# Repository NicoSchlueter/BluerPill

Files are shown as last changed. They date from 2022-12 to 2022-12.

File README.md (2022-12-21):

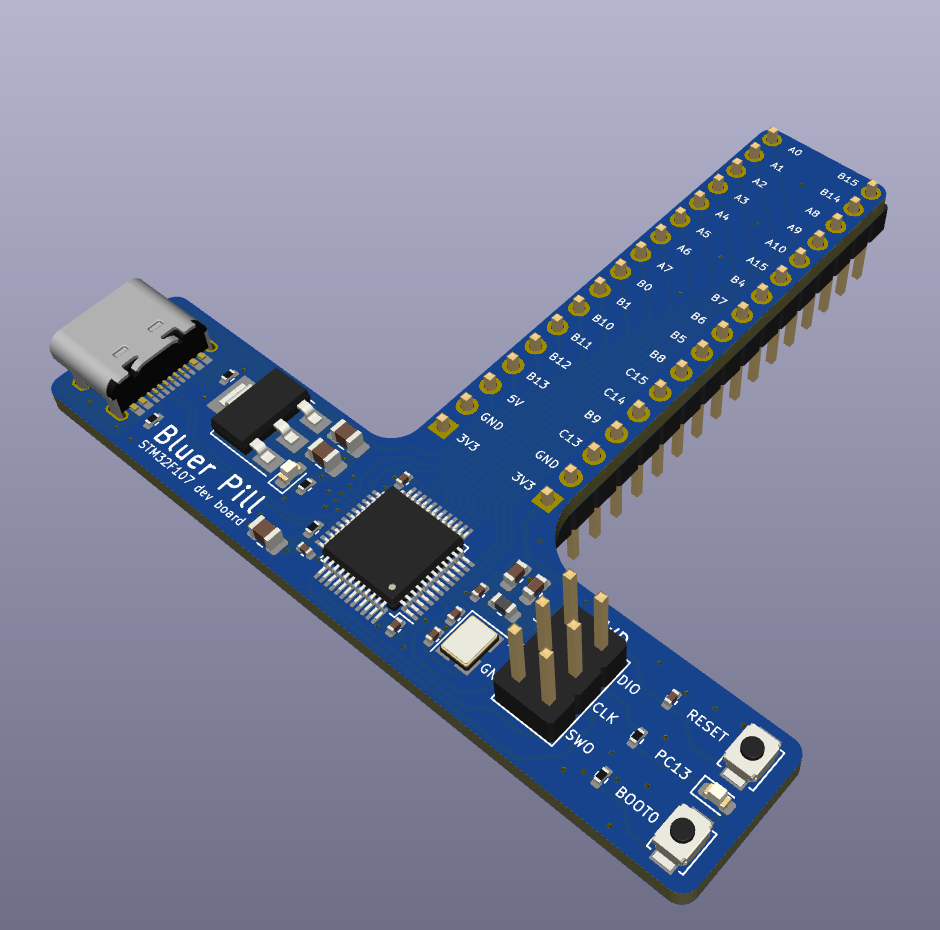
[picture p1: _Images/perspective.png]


Blue pill like STM32F103 dev board made to practice PCB design in KiCad following some Phil's lab tutorial.
 
# Things to improve
I am pretty happy with the schematic, but the routing on the board could definitly use quite some work.
I definitly underestimated the amount of signals that needed to go to the headers.

The board could probably have been designed as a two layer board as well.

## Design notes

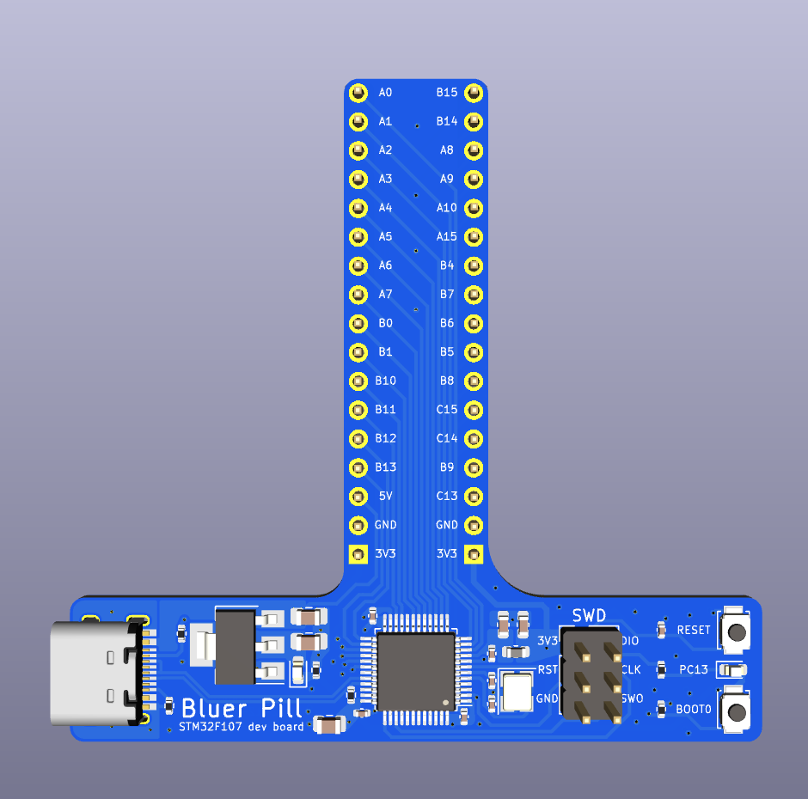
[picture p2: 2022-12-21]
_Images/top.png

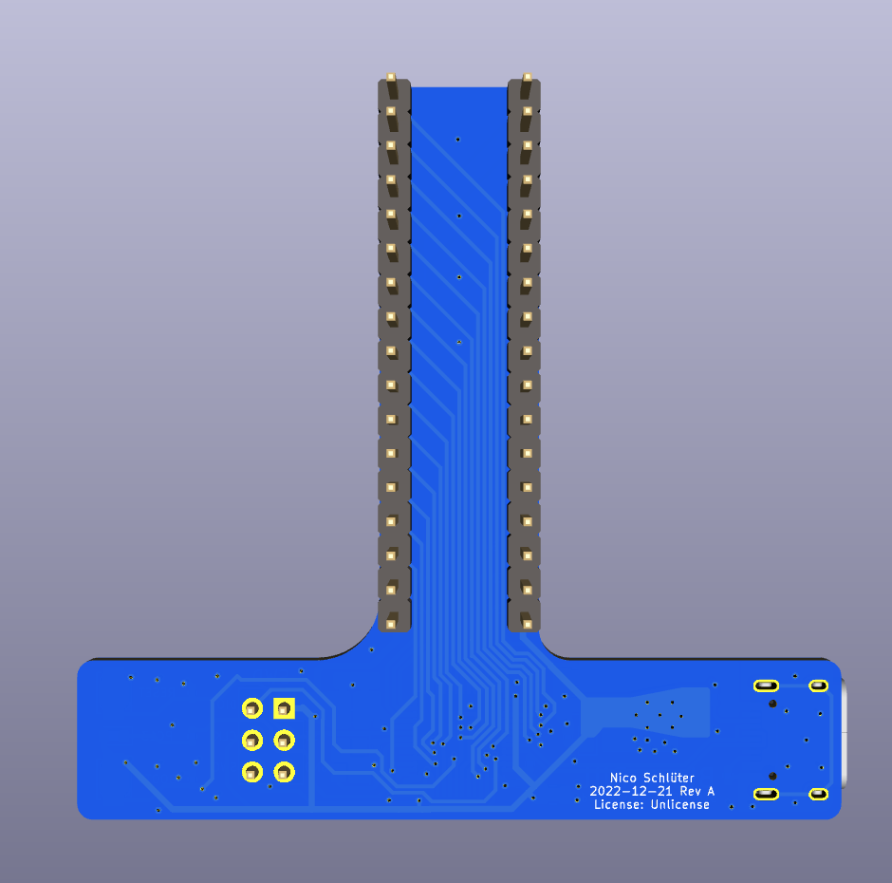
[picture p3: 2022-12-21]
_Images/bottom.png

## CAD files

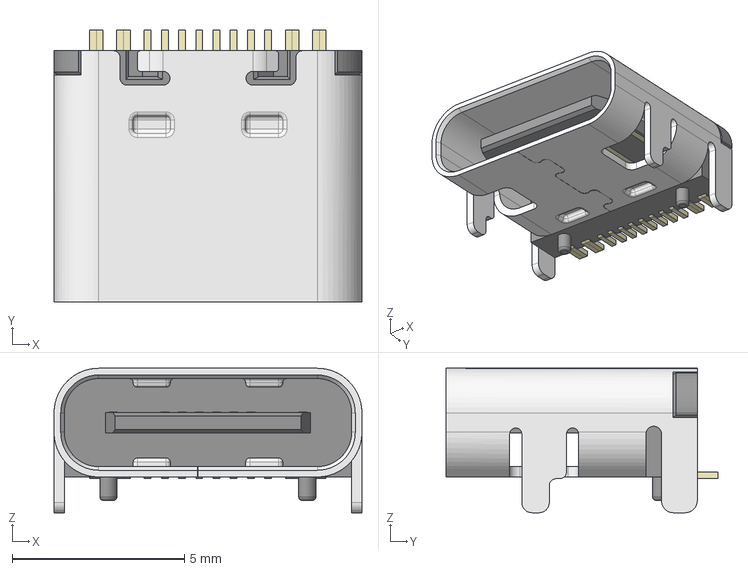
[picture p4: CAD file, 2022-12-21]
3D-Models/HRO_TYPE-C-31-M-12.step
8.95 x 7.90 x 4.20 mm

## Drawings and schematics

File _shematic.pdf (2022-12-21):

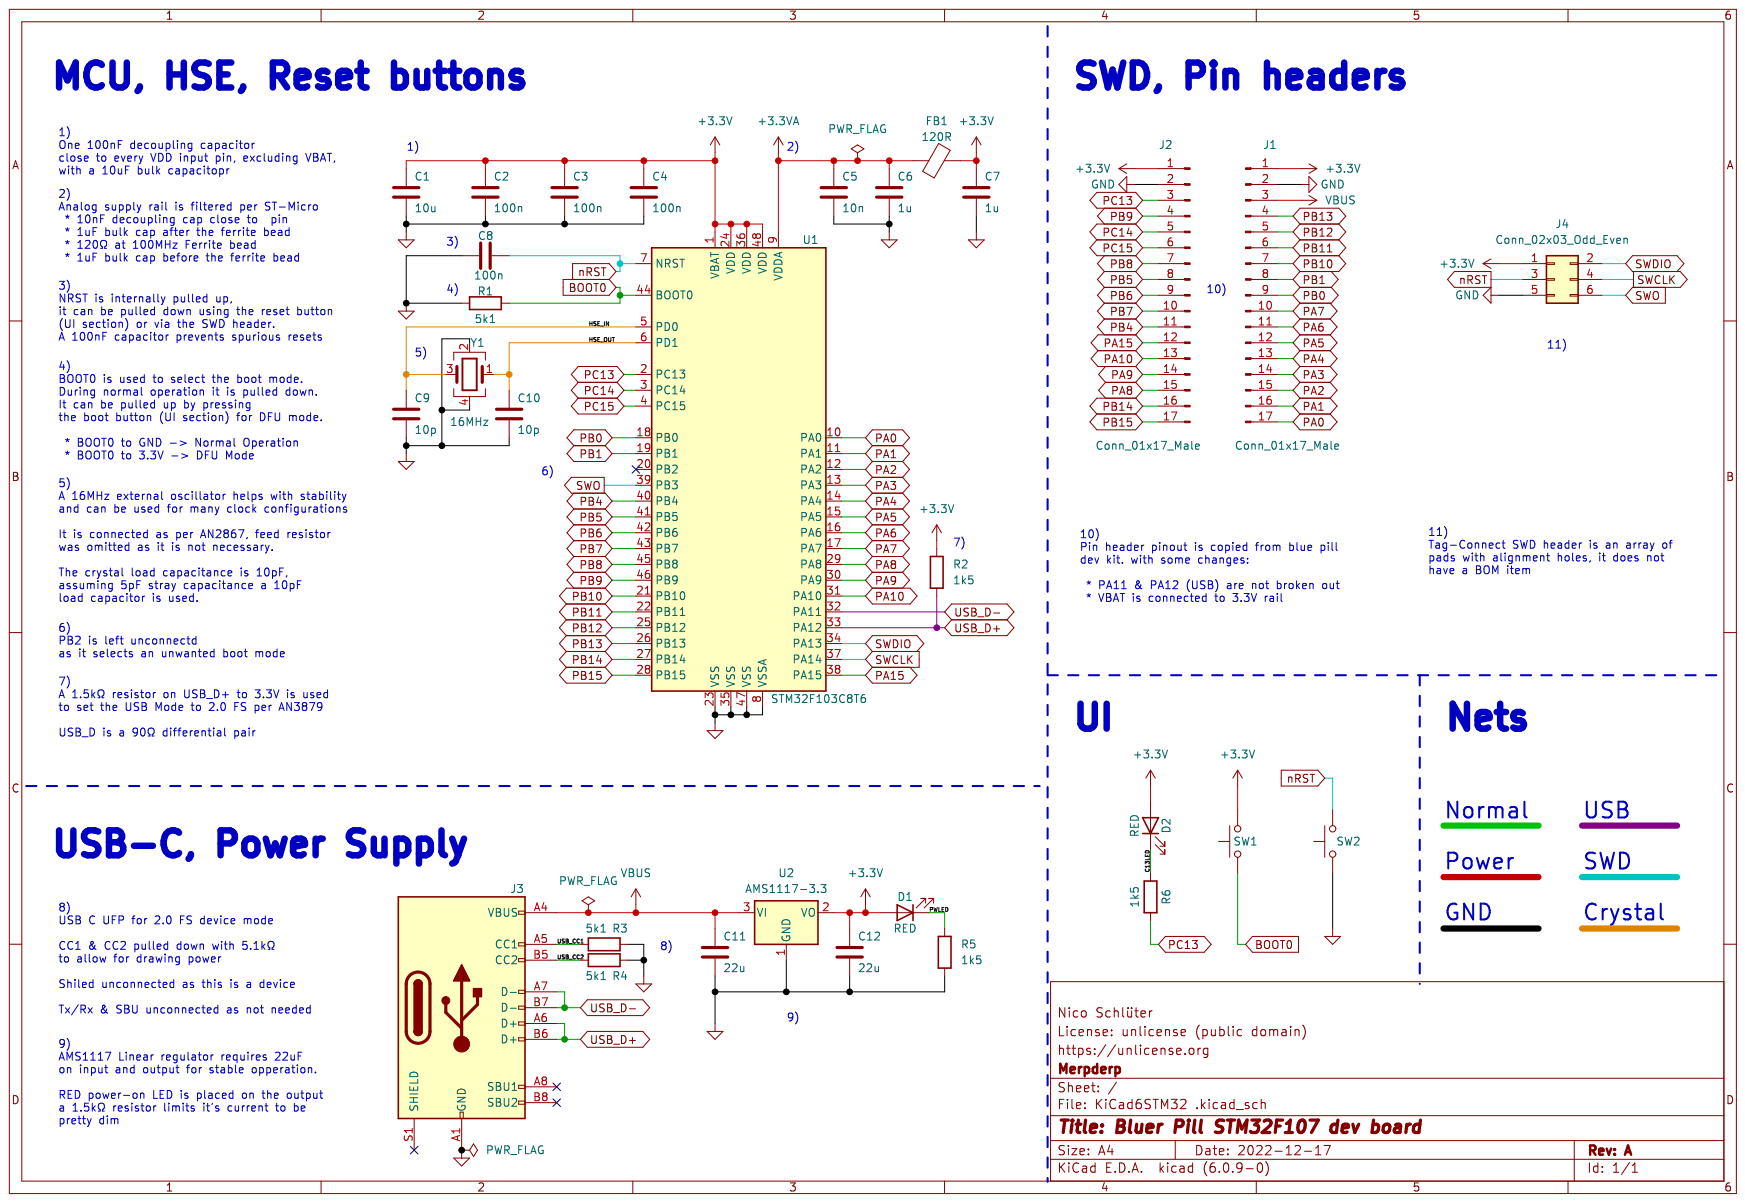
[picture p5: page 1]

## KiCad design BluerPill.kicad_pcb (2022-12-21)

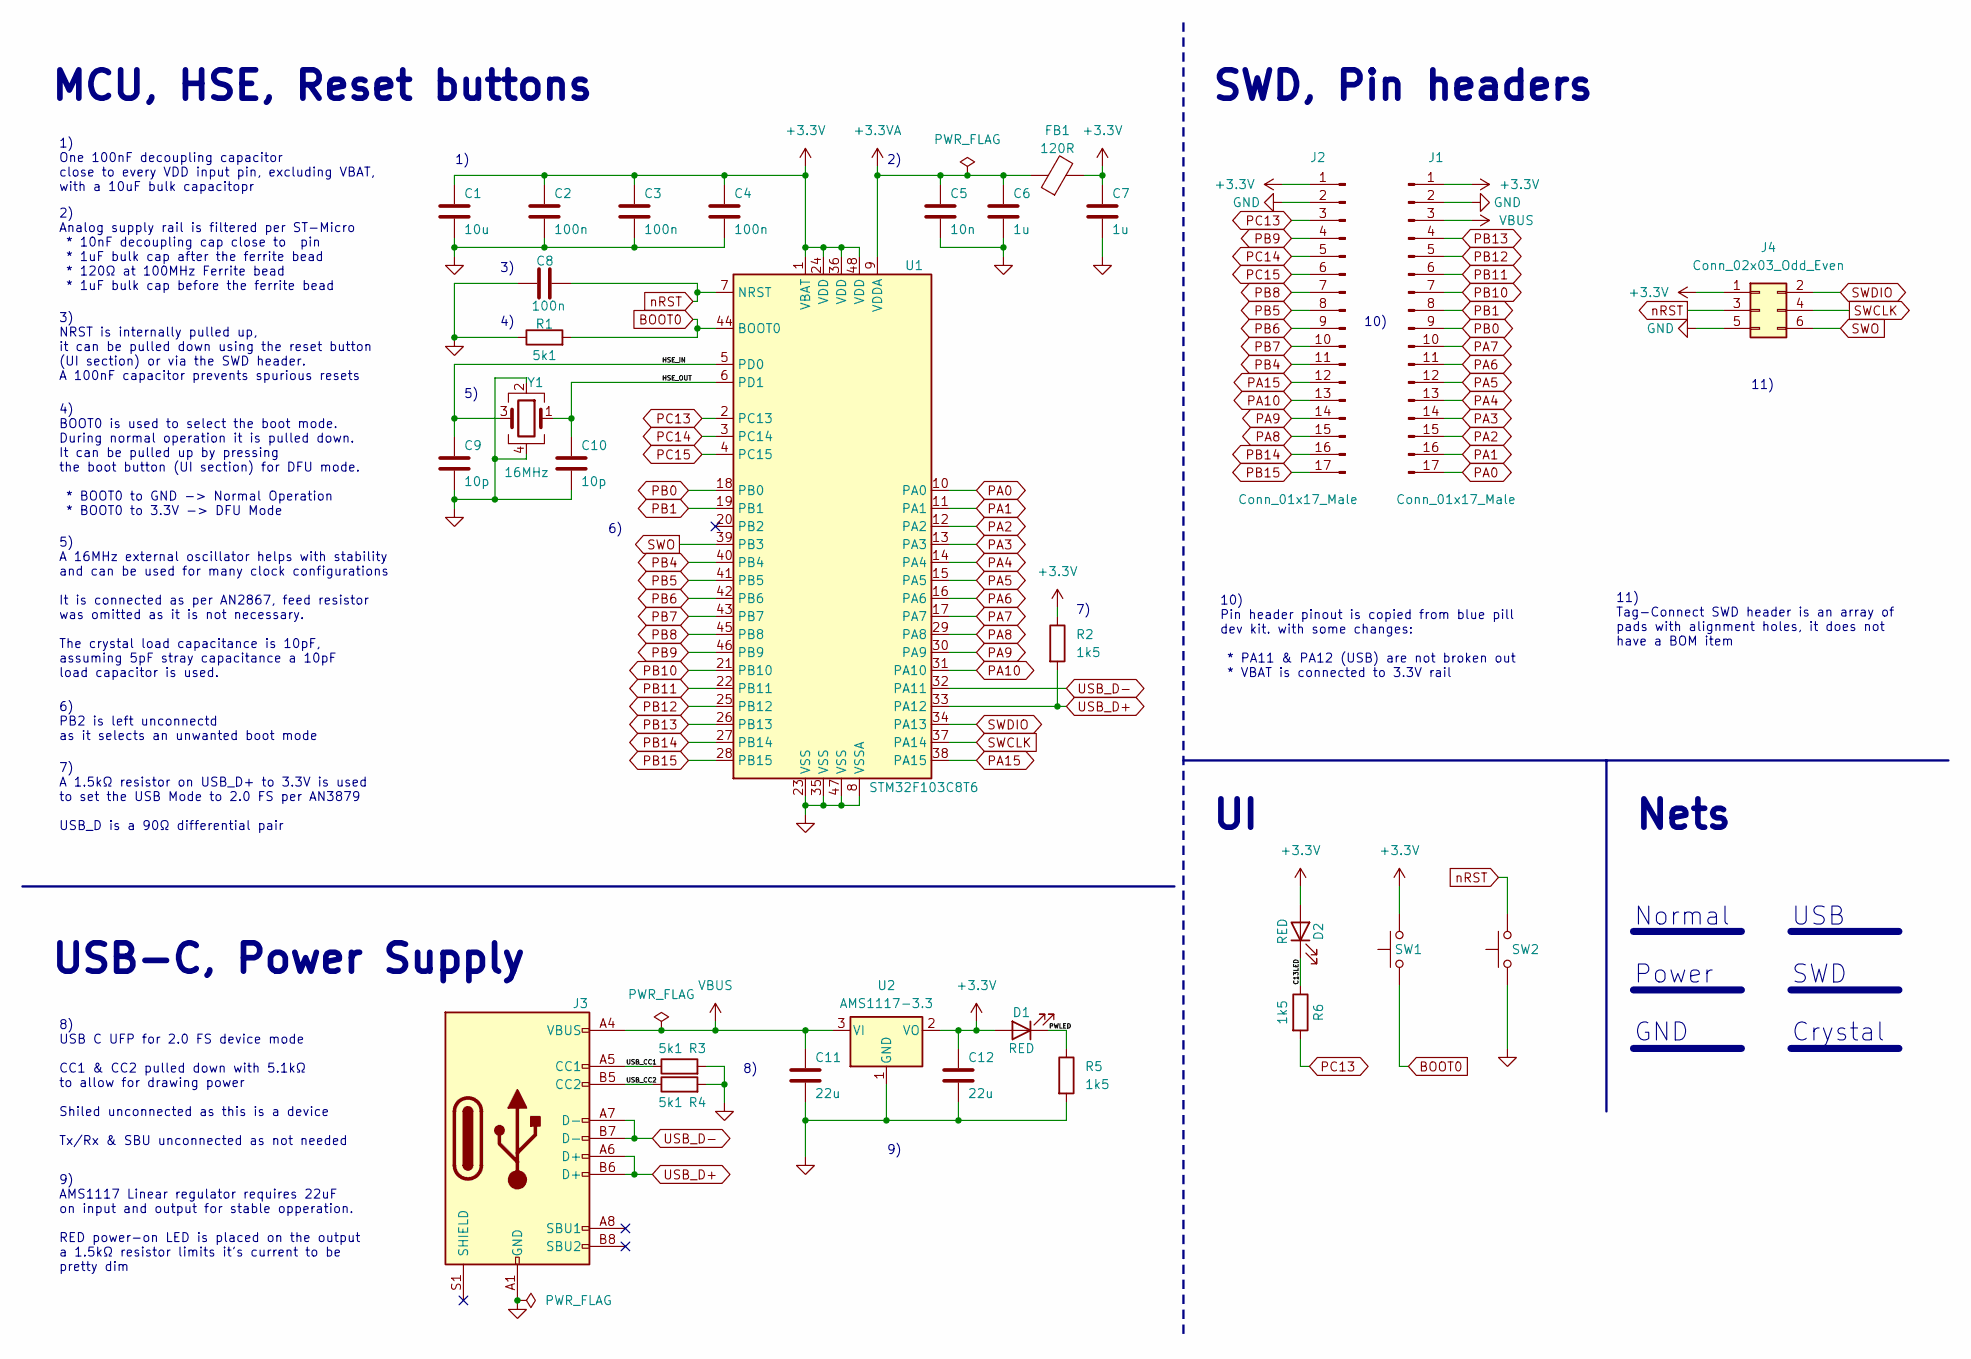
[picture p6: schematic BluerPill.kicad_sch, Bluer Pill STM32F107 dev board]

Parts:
C1: 10u; C_0805_2012Metric
C2, C3, C4, C8: 100n; C_0402_1005Metric
C5: 10n; C_0402_1005Metric
C6, C7: 1u; C_0603_1608Metric
C9, C10: 10p; C_0402_1005Metric
C11, C12: 22u; C_0805_2012Metric_Pad1.18x1.45mm_HandSolder
D1, D2: RED; LED_0603_1608Metric
FB1: 120R; L_0603_1608Metric
J1, J2: Conn_01x17_Male; PinHeader_1x17_P2.54mm_Vertical
J3: USB_C_Receptacle_USB2.0; USB_C_Receptacle_HRO_TYPE-C-31-M-12
J4: Conn_02x03_Odd_Even; PinHeader_2x03_P2.54mm_Vertical
R1, R3, R4: 5k1; R_0402_1005Metric
R2, R5, R6: 1k5; R_0402_1005Metric
SW1, SW2: SW_Push; SW_SPST_B3U-1000P
U1: STM32F103C8T6; LQFP-48_7x7mm_P0.5mm
U2: AMS1117-3.3; SOT-223-3_TabPin2
Y1: 16MHz; Crystal_SMD_3225-4Pin_3.2x2.5mm

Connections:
+3.3V: C1.1, C2.1, C3.1, C4.1, C7.1, C12.1, D1.2 (A), D2.2 (A), FB1.2, J1.1, J2.1, J4.1, R2.1, SW1.2, U1.1 (VBAT), U1.24 (VDD), U1.36 (VDD), U1.48 (VDD), U2.2 (VO)
+3.3VA: C5.1, C6.1, FB1.1, U1.9 (VDDA)
/C13LED: D2.1 (K), R6.1
/HSE_IN: C9.1, U1.5 (PD0), Y1.3
/HSE_OUT: C10.1, U1.6 (PD1), Y1.1
/PWLED: D1.1 (K), R5.1
/USB_CC1: J3.A5 (CC1), R3.1
/USB_CC2: J3.B5 (CC2), R4.1
BOOT0: R1.2, SW1.1, U1.44 (BOOT0)
GND: C1.2, C2.2, C3.2, C4.2, C5.2, C6.2, C7.2, C8.2, C9.2, C10.2, C11.2, C12.2, J1.2, J2.2, J3.A1 (GND), J3.A12 (GND), J3.B1 (GND), J3.B12 (GND), J4.5, R1.1, R3.2, R4.2, R5.2, SW2.1, U1.8 (VSSA), U1.23 (VSS), U1.35 (VSS), U1.47 (VSS), U2.1 (GND), Y1.2, Y1.4
PA0: J1.17, U1.10 (PA0)
PA1: J1.16, U1.11 (PA1)
PA2: J1.15, U1.12 (PA2)
PA3: J1.14, U1.13 (PA3)
PA4: J1.13, U1.14 (PA4)
PA5: J1.12, U1.15 (PA5)
PA6: J1.11, U1.16 (PA6)
PA7: J1.10, U1.17 (PA7)
PA8: J2.15, U1.29 (PA8)
PA9: J2.14, U1.30 (PA9)
PA10: J2.13, U1.31 (PA10)
PA15: J2.12, U1.38 (PA15)
PB0: J1.9, U1.18 (PB0)
PB1: J1.8, U1.19 (PB1)
PB4: J2.11, U1.40 (PB4)
PB5: J2.8, U1.41 (PB5)
PB6: J2.9, U1.42 (PB6)
PB7: J2.10, U1.43 (PB7)
PB8: J2.7, U1.45 (PB8)
PB9: J2.4, U1.46 (PB9)
PB10: J1.7, U1.21 (PB10)
PB11: J1.6, U1.22 (PB11)
PB12: J1.5, U1.25 (PB12)
PB13: J1.4, U1.26 (PB13)
PB14: J2.16, U1.27 (PB14)
PB15: J2.17, U1.28 (PB15)
PC13: J2.3, R6.2, U1.2 (PC13)
PC14: J2.5, U1.3 (PC14)
PC15: J2.6, U1.4 (PC15)
SWCLK: J4.4, U1.37 (PA14)
SWDIO: J4.2, U1.34 (PA13)
SWO: J4.6, U1.39 (PB3)
USB_D+: J3.A6 (D+), J3.B6 (D+), R2.2, U1.33 (PA12)
USB_D-: J3.A7 (D-), J3.B7 (D-), U1.32 (PA11)
VBUS: C11.1, J1.3, J3.A4 (VBUS), J3.A9 (VBUS), J3.B4 (VBUS), J3.B9 (VBUS), U2.3 (VI)
nRST: C8.1, J4.3, SW2.2, U1.7 (NRST)

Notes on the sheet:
10) Pin header pinout is copied from blue pill dev kit. with some changes: * PA11 & PA12 (USB) are not broken out * VBAT is connected to 3.3V rail
5) A 16MHz external oscillator helps with stability and can be used for many clock configurations It is connected as per AN2867, feed resistor was omitted as it is not necessary. The crystal load capacitance is 10pF, assuming 5pF stray capacitance a 10pF load capacitor is used.
11) Tag-Connect SWD header is an array of pads with alignment holes, it does not have a BOM item
9) AMS1117 Linear regulator requires 22uF on input and output for stable opperation. RED power-on LED is placed on the output a 1.5kΩ resistor limits it's current to be pretty dim
USB SWD Crystal
Nets
1) One 100nF decoupling capacitor close to every VDD input pin, excluding VBAT, with a 10uF bulk capacitopr
MCU, HSE, Reset buttons
10)
4) BOOT0 is used to select the boot mode. During normal operation it is pulled down. It can be pulled up by pressing the boot button (UI section) for DFU mode. * BOOT0 to GND -> Normal Operation * BOOT0 to 3.3V -> DFU Mode
2) Analog supply rail is filtered per ST-Micro * 10nF decoupling cap close to pin * 1uF bulk cap after the ferrite bead * 120Ω at 100MHz Ferrite bead * 1uF bulk cap before the ferrite bead
8) USB C UFP for 2.0 FS device mode CC1 & CC2 pulled down with 5.1kΩ to allow for drawing power Shiled unconnected as this is a device Tx/Rx & SBU unconnected as not needed
7) A 1.5kΩ resistor on USB_D+ to 3.3V is used to set the USB Mode to 2.0 FS per AN3879 USB_D is a 90Ω differential pair
Normal Power GND
SWD, Pin headers
11)
3) NRST is internally pulled up, it can be pulled down using the reset button (UI section) or via the SWD header. A 100nF capacitor prevents spurious resets
6) PB2 is left unconnectd as it selects an unwanted boot mode
USB-C, Power Supply

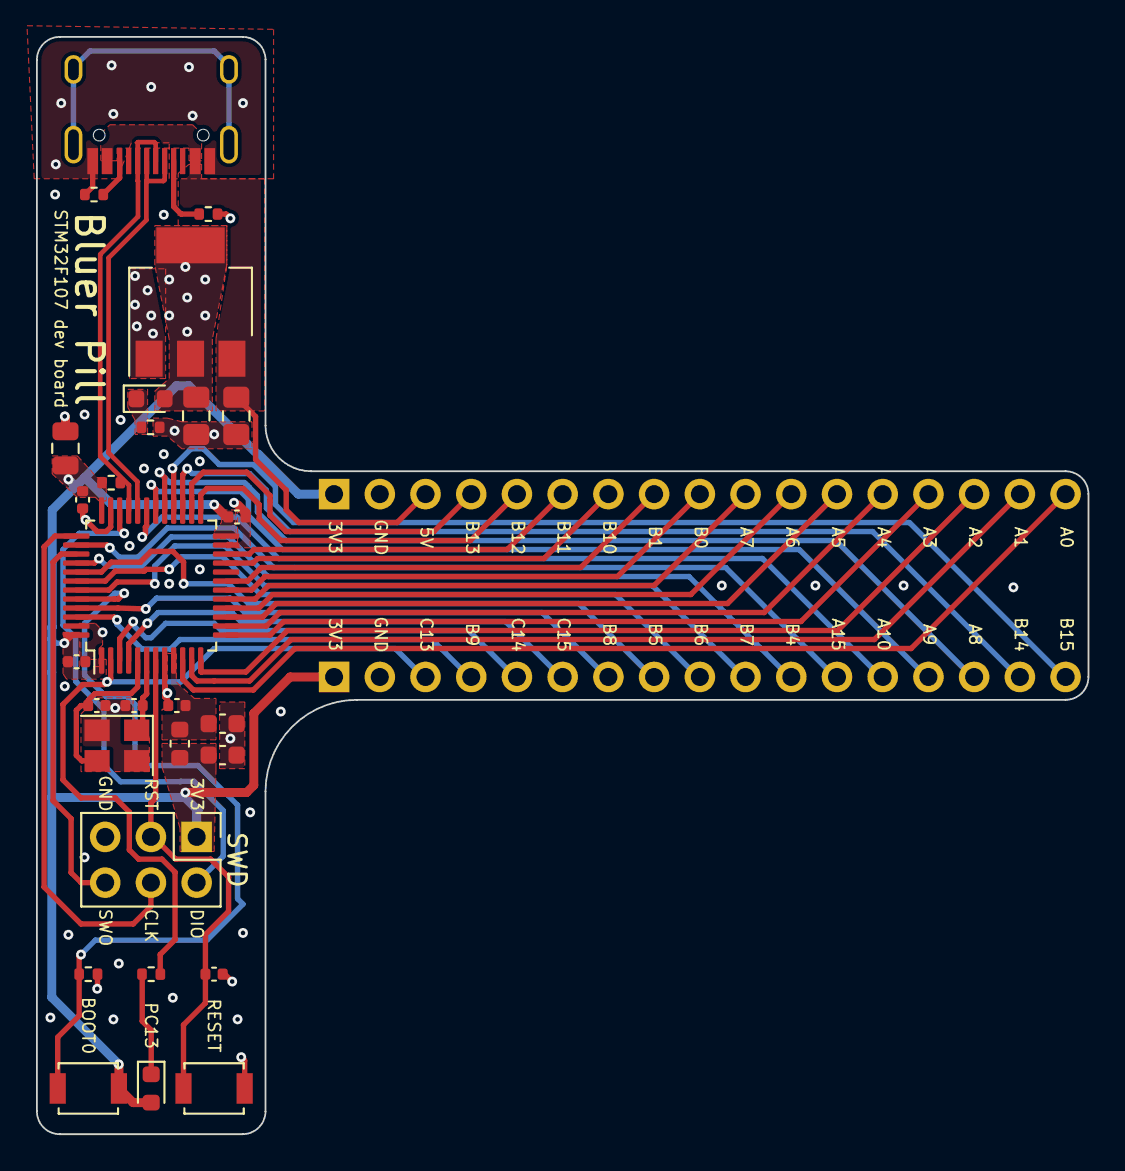
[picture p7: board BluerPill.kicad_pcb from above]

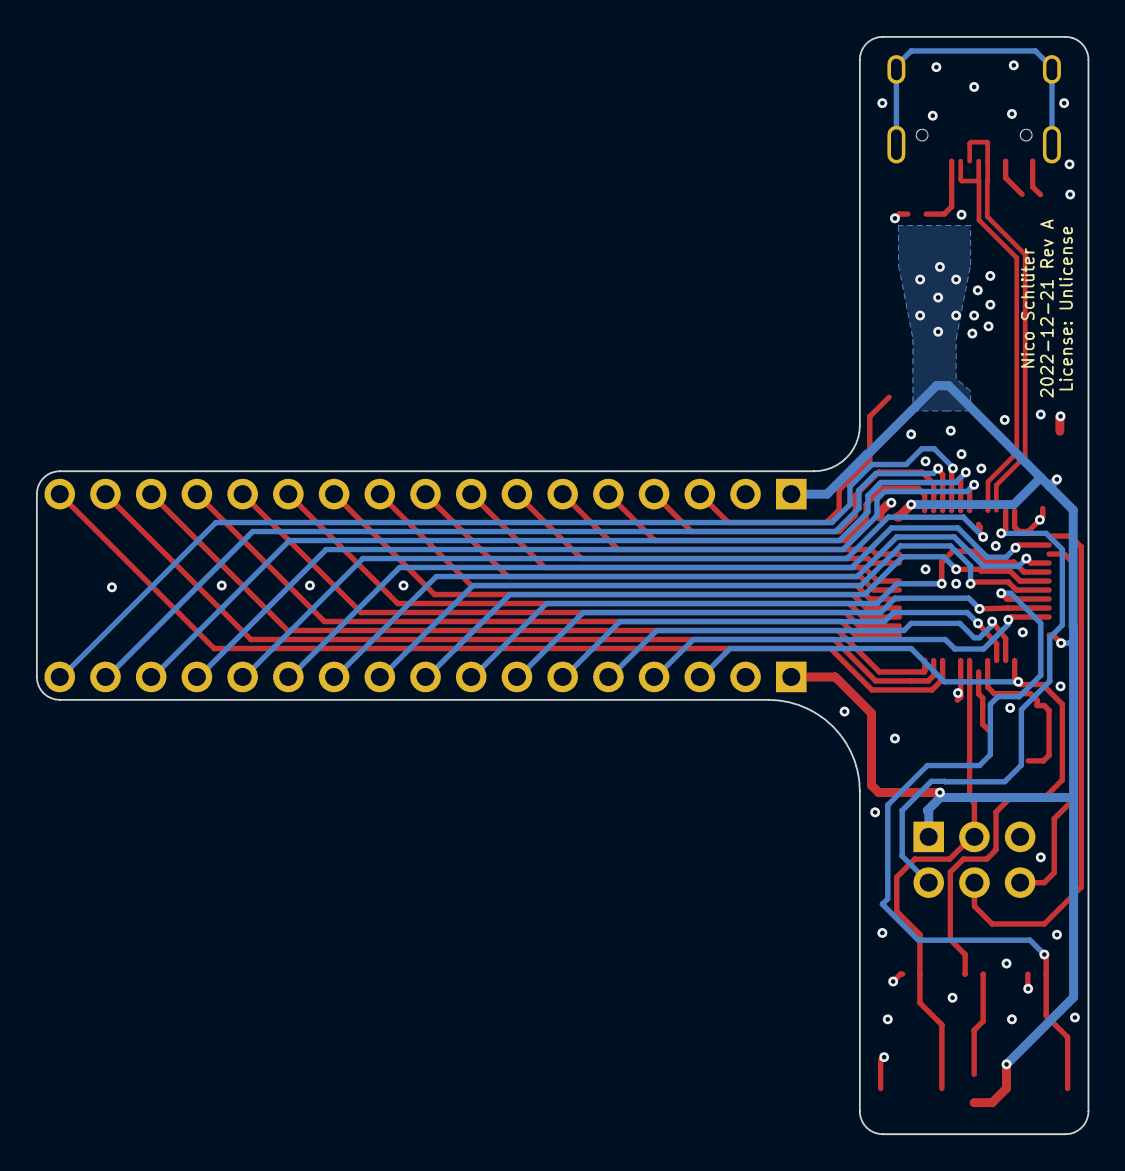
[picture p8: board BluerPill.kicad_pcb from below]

Board: 4 copper layers, 58.4 x 61.0 mm, 30 parts (2 on the bottom side), 46 nets.

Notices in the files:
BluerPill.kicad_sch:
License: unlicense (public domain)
